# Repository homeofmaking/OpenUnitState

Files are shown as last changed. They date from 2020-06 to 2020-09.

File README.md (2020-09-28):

# OpenUnitState
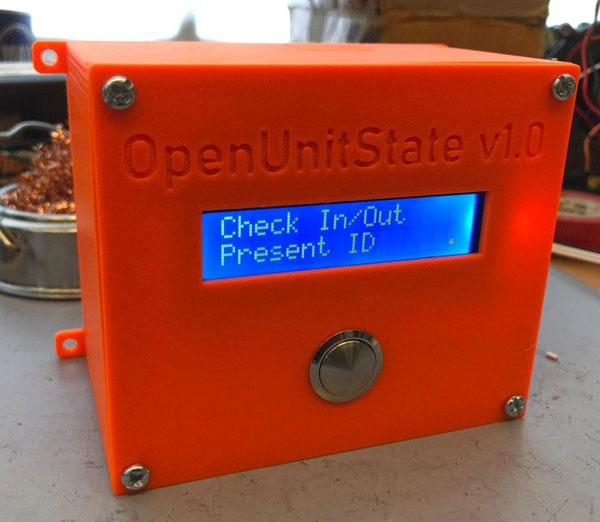
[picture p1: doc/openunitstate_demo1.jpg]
OpenUnitState Demo


An approach to "unit" status displays and authentication in open workshops and 
makerspaces. A unit can be anything from a tool found in a workshop, a 3D printer,
even a conventional printer or a kitchen stove. 

OpenUnitState aims to be "stupid by default" and therefor relies on logic 
implemented in the backend. Communication is handled through "unencrypted" MQTT
(feel free to post a pull request to enhance this). The reason for this is that we
compare OpenUnitState to a code lock on a device - if someone wants to go around
it, they will find a way to. The same holds true for OpenUnitState. It will most
likely be easier to rip out the wires of the unlocking mechanism and short them...

OpenUnitState itself consists of a hardware and a software part. The hardware 
consists mainly of an ESP8266 µC, a RC522 based card reader, a liquid crystal 
display and a button. Depending on the unit you want to control you can either 
use the 5V/VCC mosfet or a relais. The mosfet is always required, the relais is
an optional component.

OpenUnitState does indeed depend on WiFi availability. A stable WiFi and network 
setup is absolutely recommended when using OpenUnitState, however network is 
only used where necessary, e.g. updating information to the device or e.g. 
authentication requests. This is the drawback of heavily relying on off-device 
logic.

## Features
*  5 different modes to support a majority of use-cases in shared environments
    - ID to unlock (authentication required) 
    - Push to unlock
    - Permanently unlocked
    - Maintenance
    - OTA
* Information on a liquid crystal display dependant on current mode
    - Support long messages for maintenance mode /w scrolling
    - Spinner shows device is not hanging & works as intended
    - Easy to read status symbol (check for unlocked, button for push to unlock, padlock for id to unlock and skull for maintenance)
* When unlock time is close to running out, the display will start blinking
* Ability to unlock machines during maintenance mode (backend should check for permission)
* Report "unit broken" by holding the button
* WiFi manager for joining networks for easy setup and device relocation
* Stable WiFi and MQTT re-connect implemented

## Example implementations
<details>
    <summary>Demo Device</summary>
    OpenUnitState Demo
    <strong>Description:</strong> Example device used for demonstrations and development. 
    <strong>Backend:</strong> Node-Red /w Node-Red dashboard
</details>

<details>
    <summary>Check-In & Check-Out Terminal</summary>
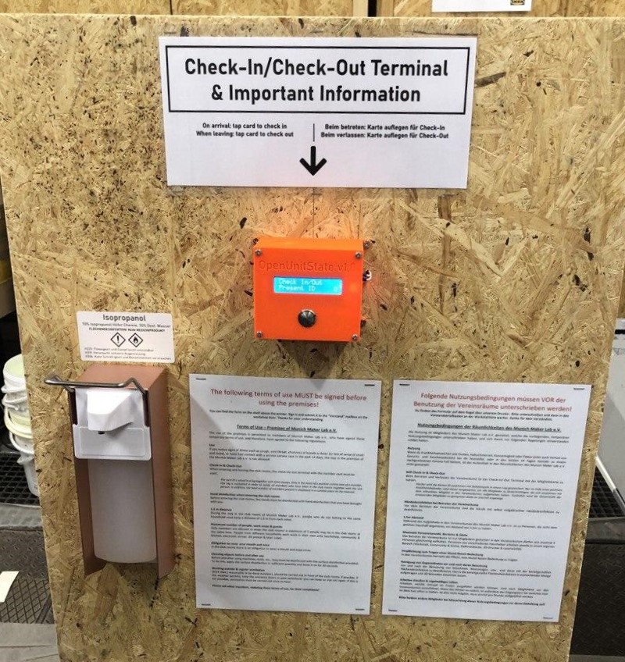
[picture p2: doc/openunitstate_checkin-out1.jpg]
OpenUnitState Check-In & Check-Out terminal
    
    <strong>Description:</strong> OpenUnitState used as a Check-In and Check-Out terminal. Part of a hygiene concept that was required by local authorities to re-open a makerspace in munich.
    <strong>Backend:</strong> Node-Red, MySQL
</details>

## MQTT connection
Right now MQTT connection needs to be configured before building the project.
`#define MQTT_TOPIC "iot/openmakerstate/"` defines the first part of the MQTT 
topic. The device will listen and write to `%MQTT_TOPIC%/%CHIP_ID%/#`

If you use `#define MQTT_TOPIC "iot/openmakerstate/"` and your ESP8266 chip id 
is c64c95 the full path would be `iot/openmakerstate/c64c95/#` (replace # with
commands found below)

## Commands MQTT > OUS
| Topic endpoint | Payload | Description |
| --- | --- | --- |
| /config_name | unitName | sets the displayed unit name |
| /config_maintenance_long_reason | maintenanceReason |  sets the long reason that is displayed when unit is in maintenance mode | 
| /config_status | 5,2,0,-1,-2,-3 |  5 = ID to unlock, 2 = push to unlock, 0 = permanently unlocked, -1 = maintenance, -2 = OTA, -3 = Check-In/Out Mode | 
| /unlocked_time | secondsToUnlock |  unlocks the machine for the given time, can be called during unlocked state to set timer again  | 
| /quick_display_msg | messageToDisplay |  Briefly displays a message on line 2 of the display | 
| /reset | - |  calls esp.restart() to hard-reset the device | 

## Commands OUS > MQTT
| Topic endpoint | Payload | Description |
| --- | --- | --- |
| /connected | (always true) | called as soon as MQTT connection is established |
| /localip | ip address | called as soon as the MQTT connection is established |
| /started | firmwareVersion | called during setup but NOT upon MQTT re-connect to indicate ESP was (re-)started |
| /ready_for_ota | chipId | as soon as device is set to mode -2 (OTA) and OTA is ready |
| /button_reported_broken | chipId | called when someone reports the device as broken using the pushbutton |
| /push_to_unlock | chipId | called on single button press when device is in push to unlock mode |
| /state_relocked | chipId | called to indicate that the device timer has run out and was re-locked |
| /card_read | hex of card | called whenever a card is presented to the reader |

## Backend design recommendations
The device boots without any configuration other than the pre-configured MQTT server. 
Therefor it is recommended to listen for the `/started` signal from OUS and 
reply with `/config_name` and `/config_status`. This initializes the device and
it is ready to use. 

If you intend to use the ID to unlock mode you should listen for `/card_read` 
and reply with an appropriate `/unlocked_time` from the backend. 

It is recommended to implement listening for `/card_read` in maintenance mode as 
well and then sending `/unlocked_time` for cards that are owned by people which
usually perform maintenance on machines.

`/card_read` could also be processed in push to unlock mode to just perform the
same action as a button press would. 

`/push_to_unlock` should be replied with `/unlocked_time` in order to unlock
the machine upon request.

## Security concerns
Please see security.md for further information on how to report vulnerabilities.

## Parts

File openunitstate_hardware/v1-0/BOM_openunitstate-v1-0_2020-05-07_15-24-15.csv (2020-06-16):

ID | Name | Designator | Footprint | Quantity | Manufacturer Part | Manufacturer | Supplier | Supplier Part | _Price | LCSC Assembly
1 | Header | H6 | HDR-TH_2P-P2.54-V-M | 1 | 2.54-1*2PFemale | BOOMELE | LCSC | C49661
2 | SS34_C8678 | D1 | DO-214AC_L4.3-W2.7-LS5.3-FD | 1 | SS34 | MDD | LCSC | C8678 |  | Yes
3 | 220 | R5 | R0805 | 1 | 0805W8F2200T5E | UniOhm | LCSC | C17557 |  | Yes
4 | SRD-05VDC-SL-C | RLY1 | RELAY-TH_SRD-XXVDC-XL-C | 1 | SRD-05VDC-SL-C | SONGLE | LCSC | C35449
5 | 100K | R3 | R0805 | 1 | 0805W8F1003T5E | UniOhm | LCSC | C17407 |  | Yes
6 | 10K | R2,R1 | R0402 | 2 | 0402WGF1002TCE | UniOhm | LCSC | C25744 |  | Yes
7 | ROHS_LOGO | LOGO1 | ROHS_LOGO_0.18_IN | 1
8 | SS54_C22452 | D2 | SMA_L4.3-W2.6-LS5.2-FD | 1 | SS54 | MDD | LCSC | C22452 |  | Yes
9 | 150 | R16 | R0402 | 1 | 0402WGF1500TCE | UniOhm | LCSC | C25082 |  | Yes
10 | 68uH | L1 | IND-SMD_L12.5-W12.5 | 1 | SWRB1205S-680MT | Sunlord | LCSC | C169388 |  | Yes
11 | XL1509-5.0E1 | U1 | SOIC-8_L5.0-W4.0-P1.27-LS6.0-BL | 1 | XL1509-5.0E1 | XLSEMI | LCSC | C61063 |  | Yes
12 | 5V Power | LED1 | LED0603-FD | 1 | KT-0603R | KENTO | LCSC | C2286 |  | Yes
13 | 19-217/BHC-ZL1M2RY/3T | LED1_BLUE | LED0603-R-RD | 1 | 19-217/BHC-ZL1M2RY/3T | EVERLIGHT | LCSC | C72041 |  | Yes
14 | 10K | R4 | R0603 | 1 | 0603WAF1002T5E | UniOhm | LCSC | C25804 |  | Yes
15 | 100uF | C5 | CAP-SMD_L3.5-W2.8-R-RD | 1 | TAJB107K006RNJ | AVX | LCSC | C16133 |  | Yes
16 | B3F-1022 | SW1 | SW-TH_4P-L6.0-W6.0-P4.50-LS6.5 | 1 | B3F-1022 | Omron Electronics | LCSC | C231317
17 | 1uF | C1 | C0805 | 1 | CL21B105KBFNNNE | SAMSUNG | LCSC | C28323 |  | Yes
18 | AO3400A | Q1 | SOT-23-3_L2.9-W1.6-P1.90-LS2.8-BR | 1 | AO3400A | AOS | LCSC | C20917 |  | Yes
19 | 220uF | C4,C3,C2 | CAP-SMD_BD10.0-L10.3-W10.3-FD | 3 | VEJ221M1HTR-1010 | LELON | LCSC | C176670 |  | Yes

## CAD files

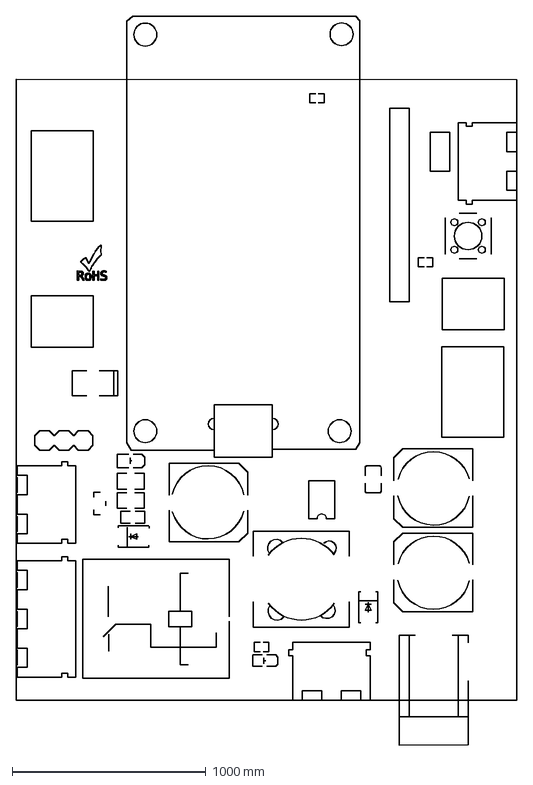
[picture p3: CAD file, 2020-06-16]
openunitstate_hardware/v1-0/openunitstate-v1-0_2020-06-01_22-51-25.dxf
2580.0 x 3760.0 mm

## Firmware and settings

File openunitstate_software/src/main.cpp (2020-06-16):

#include <Arduino.h> 
#include <SPI.h>
#include <MFRC522.h>
#include <Ticker.h>
#include <ESP8266WiFi.h>
#include <DNSServer.h>
#include <ESP8266WebServer.h>
#include <WiFiManager.h>
#include <PubSubClient.h>
#include <LiquidCrystal_I2C.h>
#include <Wire.h>
#include <ArduinoOTA.h>
#include "secret.h"

#define FW_VERSION "0.24"

// Chip ID
uint32_t chipid = ESP.getChipId();
char clientid[12];

// RFID
MFRC522 rfid(PIN_RFID_CHIP_SELECT, PIN_RFID_RESET); // Instance of the class
MFRC522::MIFARE_Key key; 
byte nuidPICC[4];

// Pre-declaration 
void setupWiFi();
void setupMQTT();
void unitLock();
void unitUnlock();
void pushToUnlockRequest();
boolean idleDisplay();
char* ip2CharArray(IPAddress IP);
String printHex(byte *buffer, byte bufferSize);

// Various objects setup
WiFiManager wifiManager;
WiFiClient espClient;
PubSubClient mqttClient(espClient);
LiquidCrystal_I2C lcd(0x27,16,2);  


// Display
String displayLineOne = "    UNKNOWN        ";
String displayLineTwo = "     ERROR         ";
char spinnerSymbols[] = {'.', 'o', 'O', 'o'};
uint8_t spinnerTick = 0;
byte lockChar[8] = {0b01110,0b10001,0b10001,0b11111,0b11011,0b11011,0b11111,0b00000};
byte checkChar[8] = {0b00000,0b00001,0b00011,0b10110,0b11100,0b01000,0b00000,0b00000};
byte skullChar[8] = {0b00000,0b01110,0b10101,0b11011,0b01110,0b01110,0b00000,0b00000};
byte buttonChar[8] = {0b00000,0b00100,0b00100,0b01110,0b00100,0b00000,0b01110,0b11111};
bool displayBlinkingState = false;
bool keepPressingToReport = false;
int displayScrollTick = 0;
int displayLongReasonLength;

// Config
String unitName = "";
String messageFlashLineTwo = "";
uint32_t unlockedTime = 0;

boolean maintenanceMode = true;
String maintenanceLongReason = "";

boolean MachineRequiresAuth = false;
boolean MachineIsPushToUnlock = false;
boolean PermUnlocked = false;
boolean WaitForOTA = false;
boolean MachineIsCheckInStation = false;

// Button config
volatile long lastDebounceTime = 0;
const int debounceDelay = 2000;

// Timers
void readCard();
void displayUpdate();
void machinerelock();
void reportBroken();
void quickdisplayclear();
Ticker timer_readcard(readCard, 100);
Ticker timer_displayupdate(displayUpdate, 1000);  
Ticker timer_machinerelock(machinerelock, 0, 1, MILLIS);
Ticker timer_reportbroken(reportBroken, 3000, 1, MILLIS);
Ticker timer_quickdisplayclear(quickdisplayclear, 5100, 1, MILLIS);



void setupWiFi() {
  lcd.clear(); lcd.print("Connecting WiFi");

  char hostName[32];
  sprintf(hostName, "%s-%06X", HOSTNAME, ESP.getChipId());
  wifi_station_set_hostname(hostName);

  if (!wifiManager.autoConnect()) {
    Serial.println("failed to connect, we should reset as see if it connects");
    lcd.clear(); lcd.print("  WiFi ERROR!");
    delay(1000);
    ESP.restart();
  }
  Serial.print(String(ESP.getChipId()) + " connected to WiFi - IP Addr. ");
  Serial.println(WiFi.localIP());

  randomSeed(micros());
}

void setupMQTT() {
  if (!mqttClient.connected()) {
    if (WiFi.status() != WL_CONNECTED) {
       return;
    }
    
    lcd.clear(); lcd.print("Connecting MQTT");

    Serial.print("Attempting MQTT connection... ");
    String mqttclientId = HOSTNAME;
    mqttclientId += String(random(0xffff), HEX);
    // Attempt to connect
    if (mqttClient.connect(mqttclientId.c_str(), MQTT_USER, MQTT_PASSWORD)) {
      Serial.println("connected");
      // Once connected, publish an announcement...
      String topic = String(MQTT_TOPIC) + String(clientid) + "/connected";
      mqttClient.publish(topic.c_str(), "true");
      // ... and resubscribe
      String sub_topic = String(MQTT_TOPIC) + String(clientid) + "/+";
      mqttClient.subscribe(sub_topic.c_str());
    } else {
      Serial.print("failed, rc=");
      Serial.print(mqttClient.state());
      Serial.println(" try again in 5 seconds");
      // Wait 5 seconds before retrying
      lcd.clear(); lcd.print("  MQTT ERROR!");
      delay(5000);
    }
  }
}

void callback(char* topic, byte* payload, unsigned int length) {
  Serial.println();
  Serial.print("Message arrived [");
  Serial.print(topic);
  Serial.print("] ");
  for (int i = 0; i < length; i++) {
    Serial.print((char)payload[i]);
  }
  Serial.println();

  char message[length];
  memcpy(message, payload, length);
  // add NULL terminator to message, making it a correct c string
  message[length] = '\0';

  Serial.print(message);

  String topic_config = String(MQTT_TOPIC) + String(clientid) + "/config_name";
  String topic_mtnc_long_reason = String(MQTT_TOPIC) + String(clientid) + "/config_maintenance_long_reason";
  String topic_quick_display_msg = String(MQTT_TOPIC) + String(clientid) + "/quick_display_msg";
  String topic_status = String(MQTT_TOPIC) + String(clientid) + "/config_status";
  String topic_ultime = String(MQTT_TOPIC) + String(clientid) + "/unlocked_time";
  String topic_reset = String(MQTT_TOPIC) + String(clientid) + "/reset";

  if (strcmp(topic, topic_config.c_str())==0) {
    unitName = String(message);
    idleDisplay();
  } else if (strcmp(topic, topic_mtnc_long_reason.c_str())==0) {
    maintenanceLongReason = String(message);
    idleDisplay();
  } else if (strcmp(topic, topic_quick_display_msg.c_str())==0) {
    timer_quickdisplayclear.start();
    messageFlashLineTwo = String(message);
  } else if (strcmp(topic, topic_ultime.c_str())==0) {
    if(!PermUnlocked) {
      unlockedTime = strtoul(String(message).c_str(), NULL, 10);
      timer_machinerelock.interval(unlockedTime);
      timer_machinerelock.start();
      unitUnlock();
    } else {
      Serial.print("Tried unlocked_time call but machine is perm unlocked...");
    }
  } else if (strcmp(topic, topic_reset.c_str())==0) {
    ESP.restart();
  } else if (strcmp(topic, topic_status.c_str())==0) {
    MachineRequiresAuth = false;
    maintenanceMode = false;
    PermUnlocked = false;
    MachineIsPushToUnlock = false;
    WaitForOTA = false;
    MachineIsCheckInStation = false;
    if ((char)payload[0] == '5') {
      // Auth required 
      MachineRequiresAuth = true;
      if(!timer_machinerelock.state() == RUNNING) {
        unitLock();
      }
    } else if ((char)payload[0] == '2') {
        // Working & Push to unlock
      MachineIsPushToUnlock = true;
      if(!timer_machinerelock.state() == RUNNING) {
        unitLock();
      }
    } else if ((char)payload[0] == '0') {
        PermUnlocked = true;
        unitUnlock();
        // Working & Unlocked permanently
    } else if ((char)payload[0] == '-') {
      if ((char)payload[1] == '1') {
        // maintenanceMode
        maintenanceMode = true;
        unitLock();
      } else if((char)payload[1] == '2') {
        maintenanceMode = true;
        WaitForOTA = true;
        unitLock();
        ArduinoOTA.begin();
        
        String topic = String(MQTT_TOPIC) + String(clientid) + "/ready_for_ota";
        mqttClient.publish(topic.c_str(), clientid);
      } else if((char)payload[1] == '3') {
        MachineIsCheckInStation = true;
      } else {
        maintenanceMode = true;
        Serial.print("Special mode not implemented.");
      }
    } else {
      maintenanceMode = true;
      Serial.print("Mode not implemented.");
    }
  }
}

void setup() { 
  Serial.begin(115200);
  SPI.begin(); // Init SPI bus

  sprintf(clientid, "%06x", chipid);

  Wire.begin(D2,D3);
  lcd.init();   // initializing the LCD
  lcd.backlight(); // Enable or Turn On the backlight 
  lcd.clear();
  lcd.print(" Initialization ");
  lcd.setCursor(0,1);
  lcd.printf("    FW %s", FW_VERSION);
  delay(2000);
  lcd.createChar(0, lockChar);
  lcd.createChar(1, checkChar);
  lcd.createChar(2, skullChar);
  lcd.createChar(3, buttonChar);

  // Outputs
  pinMode(PIN_UNIT_SWITCH, OUTPUT);
  unitLock();

  // Uncomment below to reset saved WiFi networks and 
  // show the WiFi selection again
  //wifiManager.resetSettings();
  wifiManager.setTimeout(60*5);

  setupWiFi();

  // MQTT
  mqttClient.setServer(MQTT_SERVER, 1883);
  mqttClient.setCallback(callback);
  setupMQTT();
  String topic = String(MQTT_TOPIC) + String(clientid) + "/started";
  mqttClient.publish(topic.c_str(), clientid);


  // RFID Stuff
  lcd.clear(); lcd.print("   Init. RFID");
  rfid.PCD_Init(); // Init MFRC522 

  for (byte i = 0; i < 6; i++) {
    key.keyByte[i] = 0xFF;
  }

  Serial.println(F("This code scan the MIFARE Classsic NUID."));
  Serial.print(F("Using the following key:"));
  Serial.println(printHex(key.keyByte, MFRC522::MF_KEY_SIZE));

  // OTA
  lcd.clear(); lcd.print("   Init. OTA");
  ArduinoOTA.setHostname(clientid);
  ArduinoOTA.setPassword(FLASHPW);
  ArduinoOTA.setRebootOnSuccess(false);

  ArduinoOTA.onStart([]() {
    String type;
    if (ArduinoOTA.getCommand() == U_FLASH) {
      type = "sketch";
    } else { // U_FS
      type = "filesystem";
    }

    // NOTE: if updating FS this would be the place to unmount FS using FS.end()
    Serial.println("Start updating " + type);
  });
  ArduinoOTA.onEnd([]() {
    Serial.println("\nEnd");
    lcd.clear(); 
    lcd.print("UPGRADE COMPLETE");
    delay(5000);
    ESP.restart();
  });
  ArduinoOTA.onProgress([](unsigned int progress, unsigned int total) {
    Serial.printf("Progress: %u%%\r", (progress / (total / 100)));
    lcd.clear(); 
    lcd.print("UPGRADE IN ");
    lcd.setCursor(0,1);
    lcd.printf("PROGRESS %u%%\r", (progress / (total / 100)));
  });
  ArduinoOTA.onError([](ota_error_t error) {
    timer_displayupdate.stop();
    lcd.clear(); 
    lcd.printf("OTA ERROR %u", error);
    Serial.printf("Error[%u]: ", error);
    delay(10000);
    ESP.restart();
  });

  timer_readcard.start();
  timer_displayupdate.start();

  idleDisplay();
}
 
void loop() {
  if (WiFi.status() != WL_CONNECTED) {
    setupWiFi();
  }

  if (!mqttClient.connected()) {
    setupMQTT();
  }
  mqttClient.loop();

  if(WaitForOTA) {
    ArduinoOTA.handle();
  }
  timer_readcard.update();
  timer_displayupdate.update();
  timer_machinerelock.update();
  timer_reportbroken.update();
  timer_quickdisplayclear.update();
  
}

void quickdisplayclear() {
  messageFlashLineTwo = "";
}

void reportBroken() {
  int	buttonValue = analogRead(PIN_USR_BUTTON);
	if (buttonValue>=1000 && buttonValue<=1024){
    Serial.print("reported broken");
    lcd.clear(); 
    lcd.print("   REPORTED!");
    lcd.setCursor(0,1);
    lcd.print(" RELEASE BUTTON ");

    String topic = String(MQTT_TOPIC) + String(clientid) + "/button_reported_broken";
    mqttClient.publish(topic.c_str(), clientid);
  }
  keepPressingToReport = false;
}

void pushToUnlockRequest() {
  String topic = String(MQTT_TOPIC) + String(clientid) + "/push_to_unlock";
  mqttClient.publish(topic.c_str(), clientid);
}

void unitUnlock() {
  digitalWrite(PIN_UNIT_SWITCH, HIGH);
}

void unitLock() {
  digitalWrite(PIN_UNIT_SWITCH, LOW);
}


void machinerelock() {
  timer_machinerelock.interval(0);
  timer_machinerelock.stop();
  lcd.backlight();
  unitLock();
  String topic = String(MQTT_TOPIC) + String(clientid) + "/state_relocked";
  mqttClient.publish(topic.c_str(), clientid);
}




void displayUpdate() {
  bool spinner = false;

  if (timer_machinerelock.state() == RUNNING && !keepPressingToReport) {
    displayLineOne = unitName;
  
    uint32_t sec_left = (unlockedTime-timer_machinerelock.elapsed())/1000; 
    uint16_t h; uint8_t m; uint8_t s; 
    uint32_t t = sec_left;

    s = t % 60;
    t = (t - s)/60;
    m = t % 60;
    t = (t - m)/60;
    h = t;

    if (h != 0) {
      displayLineTwo = String(h) + "h " + String(m) + "m " + String(s) + "s  rem.";
    } else {
      displayLineTwo = String(m) + "m " + String(s) + "s  rem.";
    }

    if(sec_left < 180) {
      if((displayBlinkingState) && (sec_left > 5)) {
        lcd.noBacklight();
      } else {
        lcd.backlight();
      }
      displayBlinkingState = !displayBlinkingState;
    }
  } else if(keepPressingToReport) {
    displayLineOne = "KEEP PRESSING TO";
    displayLineTwo = " REPORT BROKEN";
  } else if(messageFlashLineTwo != "") {
    displayLineTwo = messageFlashLineTwo;
  } else {
    spinner =  idleDisplay();
  }

  lcd.clear(); 
  lcd.print(displayLineOne);
  lcd.setCursor(0,1);
  
  displayLongReasonLength = displayLineTwo.length();
  if(maintenanceMode && (displayLongReasonLength > 16) && (timer_machinerelock.state() != RUNNING)) {
    String toShow;
    toShow = displayLineTwo.substring(displayScrollTick,displayScrollTick+16);
    displayScrollTick = displayScrollTick + 2;
      if(displayScrollTick>(displayLongReasonLength-16)) {
        displayScrollTick = 0;
      }
    lcd.print(toShow);
  } else {
    lcd.print(displayLineTwo);
  }
  

  
  if(maintenanceMode) {
    lcd.setCursor(15, 0);  
    lcd.write(byte(2));
  } else if(PermUnlocked or (timer_machinerelock.state() == RUNNING)) {
    lcd.setCursor(15, 0);  
    lcd.write(byte(1));
  } else if(MachineIsPushToUnlock) {
    lcd.setCursor(15, 0);  
    lcd.write(byte(3));
  } else if(MachineRequiresAuth) {
    lcd.setCursor(15, 0);  
    lcd.write(byte(0));
  }
  
  if(spinner) {
    lcd.setCursor(15,1);
    lcd.write(spinnerSymbols[spinnerTick%4]);
    spinnerTick = (spinnerTick+1) & 0b11;
  }

}

boolean idleDisplay() {
  if (unitName.equals(String("")) and !WaitForOTA) {
    displayLineOne = " Not configured";
    displayLineTwo = "     " + String(clientid);
  } else if (WaitForOTA) {
    displayLineOne = "OTA MODE " + String(clientid);
    displayLineTwo = String((char*) ip2CharArray(WiFi.localIP()));
  } else if (maintenanceMode) {
    displayLineOne = unitName;
    if(!maintenanceLongReason.equals(String(""))) {
      displayLineTwo = maintenanceLongReason;
      displayLongReasonLength = displayLineTwo.length();
      if (displayLongReasonLength < 16) {
        return true;
      } else {
        return false;
      }
    } else {
      displayLineTwo = "!SERVICE MODE!";
    }
  } else if (PermUnlocked) {
    displayLineOne = unitName;
    displayLineTwo = "Ready";
  } else if (MachineIsPushToUnlock) {
    displayLineOne = unitName;
    displayLineTwo = "Push to unlock";
  } else if (MachineRequiresAuth) {
    displayLineOne = unitName;
    displayLineTwo = "ID to unlock";
  } else if (MachineIsCheckInStation) {
    displayLineOne = unitName;
    displayLineTwo = "Present ID";
  }
  return true;
}

void readCard() {
  if(!keepPressingToReport) {
    int	buttonValue = analogRead(PIN_USR_BUTTON);
    if (buttonValue>=1000 && buttonValue<=1024){
      if((millis() - lastDebounceTime) <= debounceDelay) {
         // Debounce funcs here
       } else {
        // Not debouncing
        if(timer_machinerelock.state() == RUNNING) {
          machinerelock();
        } else if (MachineIsPushToUnlock) {
          pushToUnlockRequest();
        } else if (maintenanceMode) {
          // nothing for now. 
        } else {
          Serial.print("Should send 'not working'");
          keepPressingToReport = true;
          timer_reportbroken.start();
        }
         lastDebounceTime = millis();
      }
    }
  }


  // Reset the loop if no new card present on the sensor/reader. This saves the entire process when idle.
  if ( ! rfid.PICC_IsNewCardPresent())
    return;

  // Verify if the NUID has been readed
  if ( ! rfid.PICC_ReadCardSerial())
    return;

  Serial.print(F("PICC type: "));
  MFRC522::PICC_Type piccType = rfid.PICC_GetType(rfid.uid.sak);
  Serial.println(rfid.PICC_GetTypeName(piccType));

  // Check is the PICC of Classic MIFARE type
  /** if (piccType != MFRC522::PICC_TYPE_MIFARE_MINI &&  
    piccType != MFRC522::PICC_TYPE_MIFARE_1K &&
    piccType != MFRC522::PICC_TYPE_MIFARE_4K) {
    Serial.println(F("Your tag is not of type MIFARE Classic."));
    return;
  } **/

  /**if (rfid.uid.uidByte[0] != nuidPICC[0] || 
    rfid.uid.uidByte[1] != nuidPICC[1] || 
    rfid.uid.uidByte[2] != nuidPICC[2] || 
    rfid.uid.uidByte[3] != nuidPICC[3] ) {
    Serial.print(F("Card NUID tag: ")); **/

    // Store NUID into nuidPICC array
    for (byte i = 0; i < 4; i++) {
      nuidPICC[i] = rfid.uid.uidByte[i];
    }
   
    Serial.print(printHex(rfid.uid.uidByte, rfid.uid.size));
    Serial.println();

    String topic = String(MQTT_TOPIC) + String(clientid) + String("/card_read");
    mqttClient.publish(topic.c_str(), String(printHex(rfid.uid.uidByte, rfid.uid.size)).c_str());
  
 /** } else Serial.println(F("Card read previously.")); **/

  // Halt PICC
  rfid.PICC_HaltA();

  // Stop encryption on PCD
  rfid.PCD_StopCrypto1();
}


/**
 * Helper routine to dump a byte array as hex values to Serial. 
 */
String printHex(byte *buffer, byte bufferSize) {
  String id = "";
  for (byte i = 0; i < bufferSize; i++) {
    id += buffer[i] < 0x10 ? "0" : "";
    id += String(buffer[i], HEX);
  }
  return id;
}

char* ip2CharArray(IPAddress IP) {
  static char a[16];
  sprintf(a, "%d.%d.%d.%d", IP[0], IP[1], IP[2], IP[3]);
  return a;
}

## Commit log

2020-06-16 demo device image
2020-09-28 Update README.md
    📖 updated modes and behavior for new fw version
